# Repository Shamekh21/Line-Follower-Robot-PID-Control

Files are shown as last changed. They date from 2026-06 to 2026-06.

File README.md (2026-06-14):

# Line-Follower-Robot-PID-Control

An autonomous high-speed Line Follower Robot developed as part of the **Mobile Robots (MAM331)** course at **Benha University - Faculty of Engineering**.

The robot was designed, assembled, programmed, and tested to follow a predefined path using a **5-sensor infrared array** and a **PID control algorithm** for accurate and stable navigation.

The project successfully participated in a line follower competition organized during the course, achieving one of the fastest completion times on the track.

---

## 📸 Robot Design

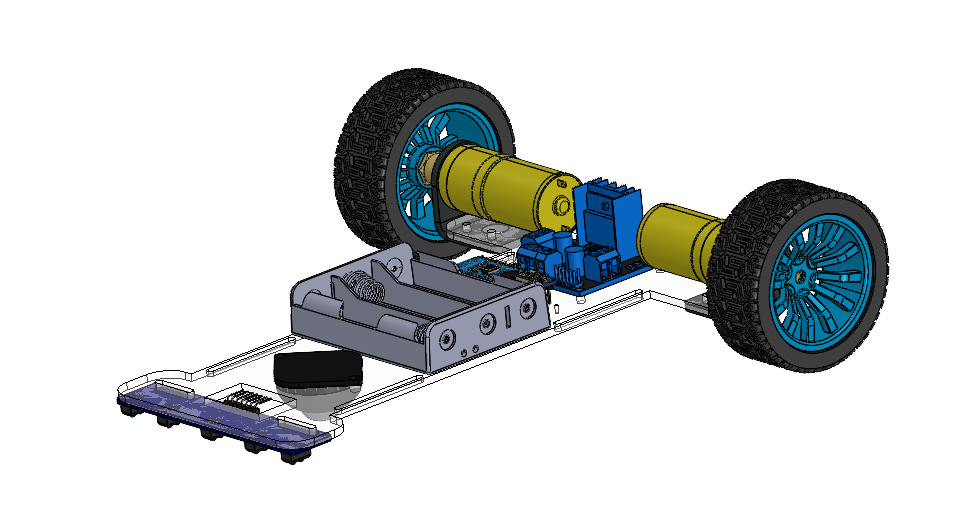
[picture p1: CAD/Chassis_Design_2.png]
Robot Design


The robot chassis was designed and assembled using **SolidWorks**, focusing on lightweight construction, stability, and efficient sensor placement for optimal line tracking performance.

---

## 🎥 Demonstration



---

# 🚀 Project Features

- Autonomous line tracking
- PID-based steering correction
- High-speed navigation
- Real-time sensor processing
- Lost-line recovery mechanism
- Optimized turning behavior
- Motor calibration support
- Differential drive locomotion
- Custom mechanical design

---
--# System Architecture

```text
IR Sensor Array
       │
       ▼
Error Calculation
       │
       ▼
PID Controller
       │
       ▼
Motor Speed Correction
       │
       ▼
L298N Driver
       │
       ▼
DC Motors
       │
       ▼
Robot Motion
```
---

# ⚙️ Hardware Components

| Component | Description |
|---|---|
| Arduino nano | Main controller |
| L298N Motor Driver | Motor control |
| 2 DC Geared Motors | Robot locomotion(DC Gear Motor JGA25-370 (780RPM - 12V)) |
| 5 IR Line Sensors | Line detection(TCRT5000 Tracking Line Follower Sensor) |
| Caster Wheel | Balance and support |
| Li-ion Battery Pack | Power supply |
| Custom Chassis | Mechanical structure |

---
# 📷 Hardware Overview

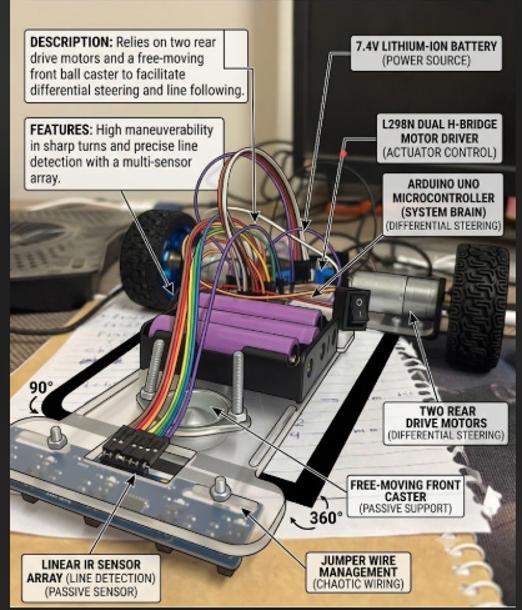
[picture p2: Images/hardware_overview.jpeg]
Hardware Overview


The figure illustrates the main hardware architecture of the robot, including the Arduino controller, L298N motor driver, infrared sensor array, differential drive system, battery pack, and chassis layout.
---
# 🧠 Control Strategy

The robot uses a **PID (Proportional-Integral-Derivative) Controller** to continuously minimize the tracking error between the robot's position and the detected line.

### PID Controller Advantages

- Smooth movement
- Fast response
- Reduced oscillation
- Improved stability at high speed
- Better corner handling

The implemented controller combines:

- Proportional Term (P)
- Integral Term (I)
- Derivative Term (D)

to generate steering corrections in real time.

---

# 📡 Sensor Configuration

The robot uses five infrared sensors positioned at the front of the chassis.

```text
[S1] [S2] [S3] [S4] [S5]
```

### Error Mapping

| Sensor Position | Error |
|---|---|
| Far Left | -2 |
| Left | -1 |
| Center | 0 |
| Right | +1 |
| Far Right | +2 |

This error value is used by the PID controller to calculate steering corrections.

---

# 🔧 Software Features

### Real-Time Sensor Reading

The robot continuously reads the state of all sensors to determine line position.

### PID Correction

Motor speeds are dynamically adjusted based on tracking error.

### Lost Line Recovery

If the line is temporarily lost, the robot automatically rotates toward the last known line direction until the path is detected again.

### Motor Calibration

Independent calibration values are included for left and right motors to compensate for hardware differences.

### High-Speed Optimization

The PID gains were experimentally tuned to achieve stable operation while maintaining high tracking speed.

---

# 🏎️ Competition Performance

The robot was tested during the Mobile Robots course competition.

### Achievements

- Successfully completed the course
- Stable tracking at high speed
- Accurate corner handling
- Fast recovery from tracking errors
- One of the fastest completion times during the competition

---

# 🛠️ Development Workflow

1. Mechanical Design using SolidWorks
2. Chassis Manufacturing and Assembly
3. Sensor Integration
4. Motor Driver Configuration
5. Arduino Programming
6. PID Tuning
7. Testing and Validation
8. Competition Deployment

---

# 💻 Technologies Used

- Arduino IDE
- Embedded C/C++
- PID Control
- SolidWorks
- Mobile Robotics
- Sensor-Based Navigation
- Differential Drive Systems

---

# 📚 Course

**Mobile Robots (MAM331)**

Faculty of Engineering  
Benha University

---

# 👨‍🏫 Supervision

**Dr. Muhammed Gaafar**

**Eng. Ahmed Adel Ghoneimy**

---

# 👥 Team Members

- Mahmoud Mohamed Shamekh
- Mohsen Hany Mohsen
- Youssef Ayad
- Barthinia Hany

---

# 🔗 GitHub Repository

Repository Link:

```
https://github.com/Shamekh21/Line-Follower-Robot-PID-Control.git
```

---

# 📌 Keywords

Robotics • Mobile Robots • Arduino • PID Control • Line Follower • Embedded Systems • Control Systems • Automation • Mechatronics • SolidWorks • Engineering

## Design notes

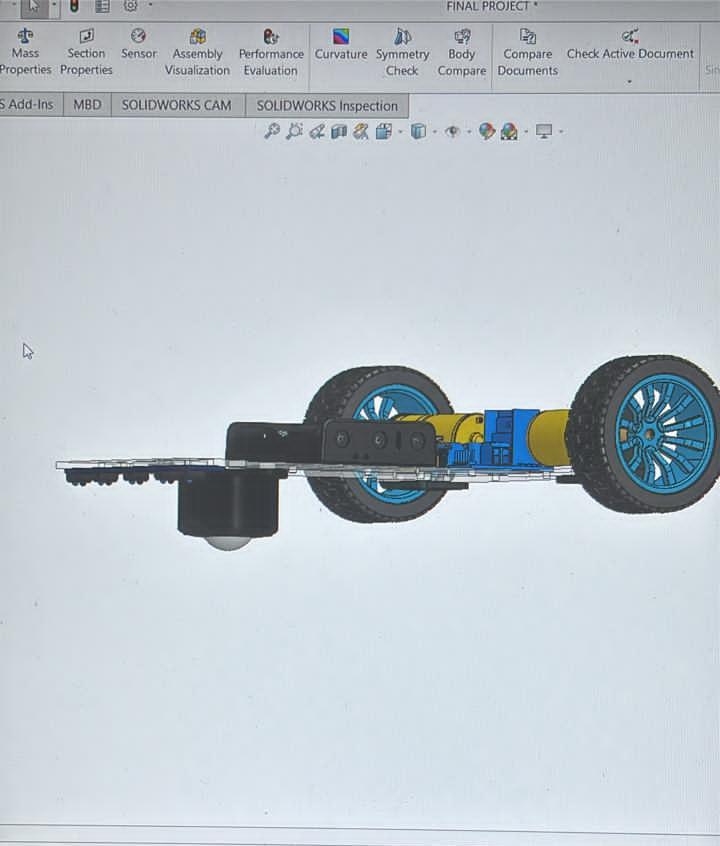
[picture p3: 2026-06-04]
CAD/line folower solid_3.jpeg

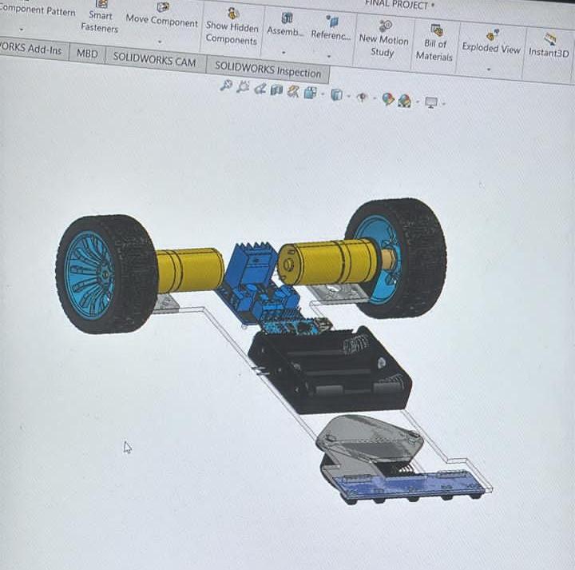
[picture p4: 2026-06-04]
CAD/line folower solid_2.jpeg

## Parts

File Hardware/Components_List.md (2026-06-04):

Arduino nano

L298N Motor Driver

2 DC Geared Motors:DC Gear Motor JGA25-370 (780RPM - 12V)

5 IR Line Tracking Sensors:TCRT5000 Tracking Line Follower Sensor

Caster Wheel

Li-ion Battery Pack

Custom Chassis Design

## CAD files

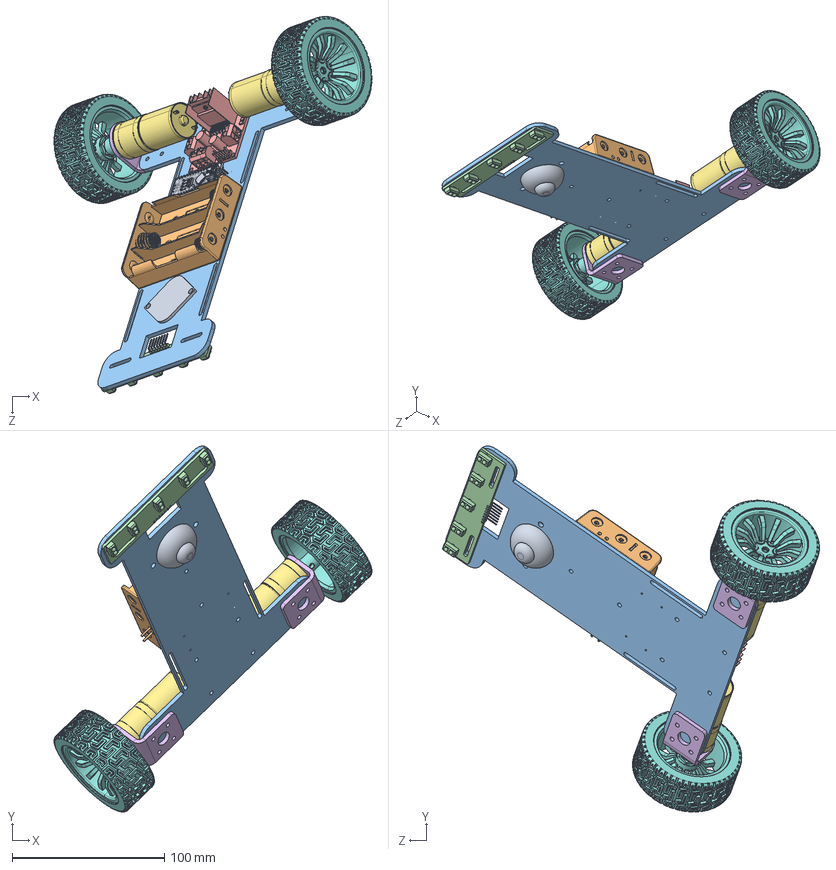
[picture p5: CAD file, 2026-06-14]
CAD/FINAL PROJECT.SLDASM
208.6 x 240.2 x 247.5 mm
Arduino_NANO_CH340.step
batteryCase18650x3.step
CHASSIS
IR sensor array.step
L298N Motor Driver.STEP
Motor Bracket JGA25.stp x 2
motor.STEP x 2
65mm蓝色轮胎总装-实际外径68mm.STEP x 2
BALL CASTER WHEEL

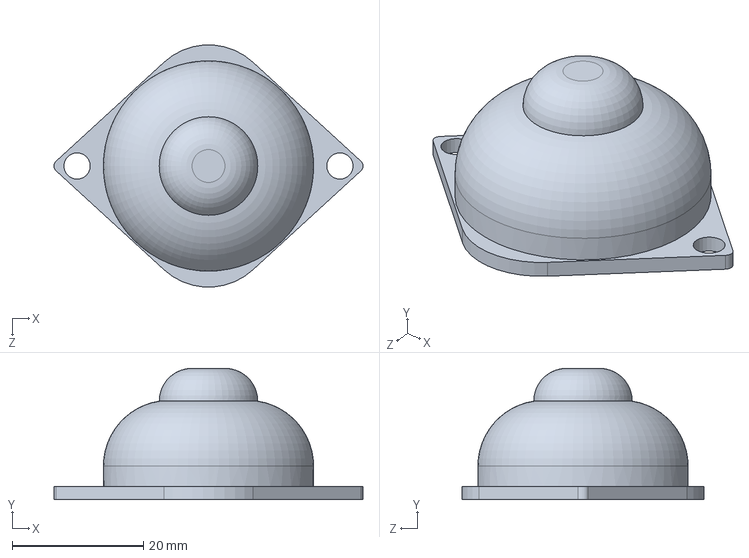
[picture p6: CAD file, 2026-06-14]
CAD/BALL CASTER WHEEL.SLDPRT
47.0 x 20.0 x 36.8 mm

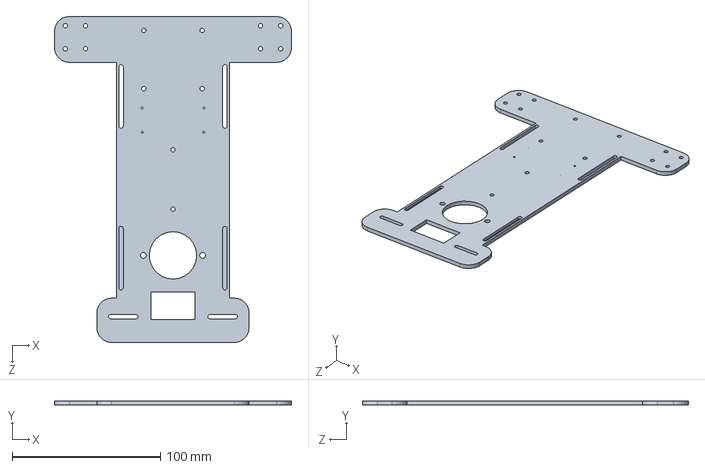
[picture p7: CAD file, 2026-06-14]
CAD/CHASSIS.SLDPRT
160.0 x 3.00 x 220.0 mm

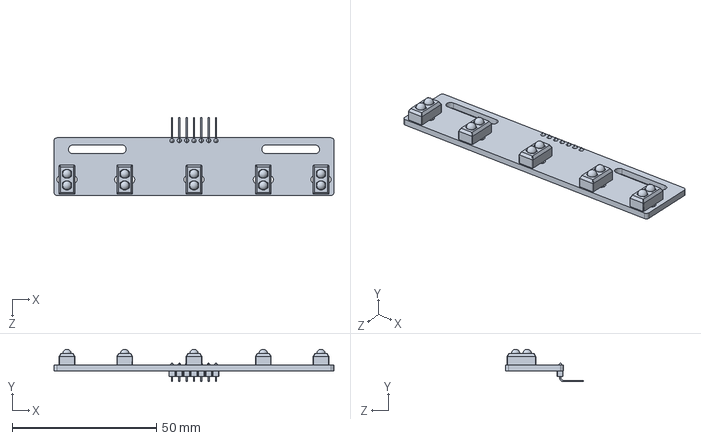
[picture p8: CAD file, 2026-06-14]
CAD/IR sensor array.step.SLDPRT
97.0 x 11.2 x 27.0 mm

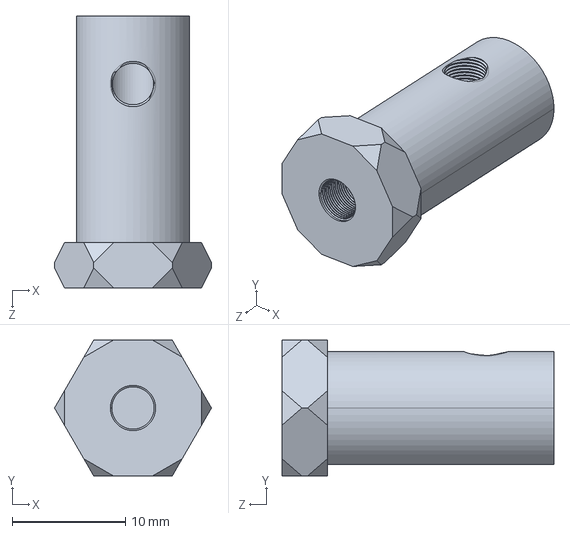
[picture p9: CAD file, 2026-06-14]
CAD/Coupler_4mm.STEP
13.9 x 12.0 x 24.0 mm

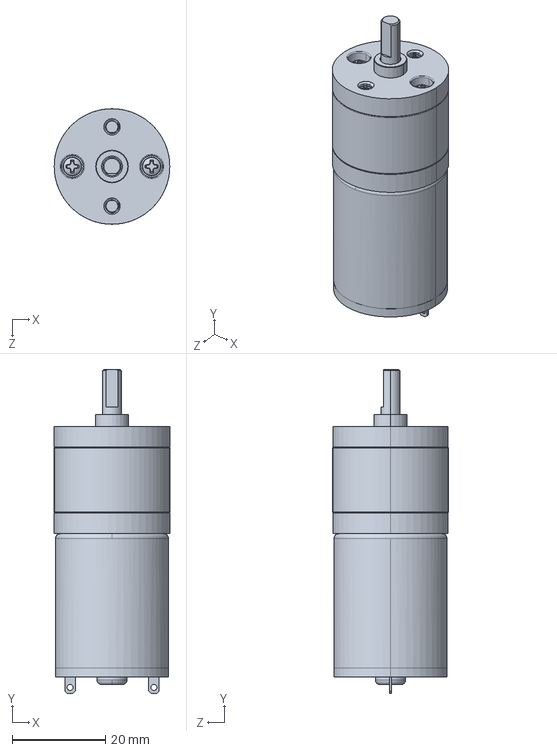
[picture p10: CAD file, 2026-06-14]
CAD/motor.STEP.SLDPRT
24.8 x 69.5 x 24.8 mm

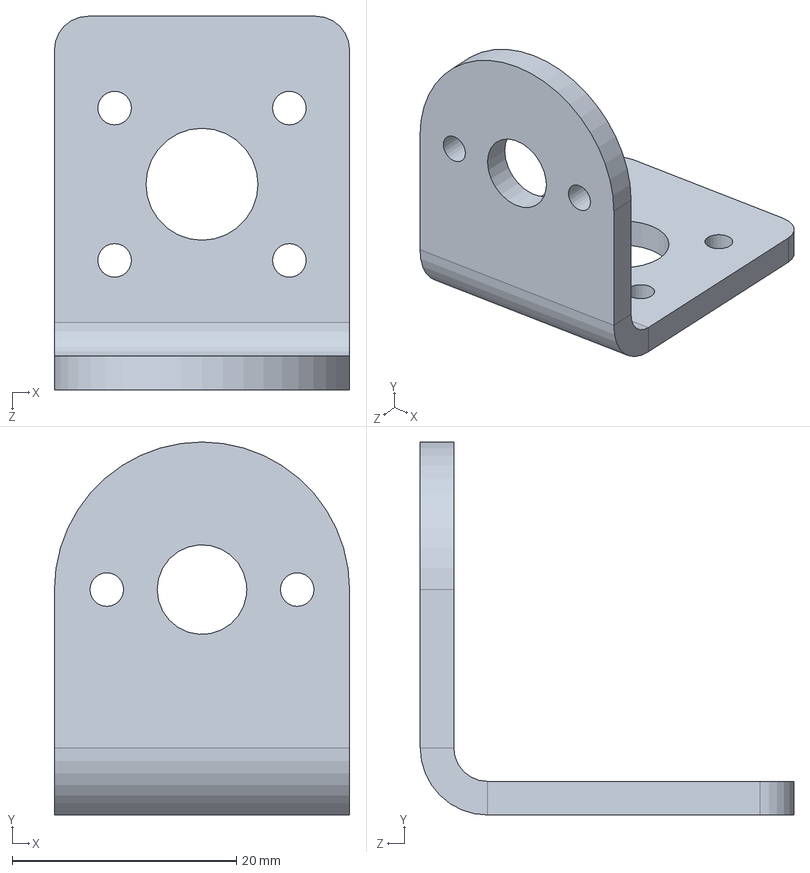
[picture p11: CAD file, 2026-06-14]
CAD/Motor Bracket JGA25.stp.SLDPRT
26.4 x 33.3 x 33.3 mm

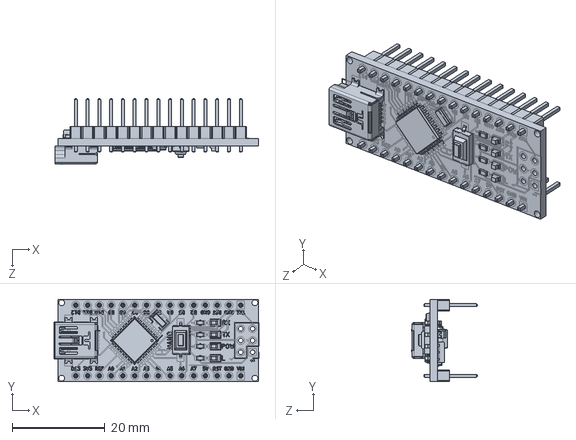
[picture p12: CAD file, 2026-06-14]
CAD/Arduino_NANO_CH340.step.SLDPRT
44.2 x 17.8 x 14.1 mm

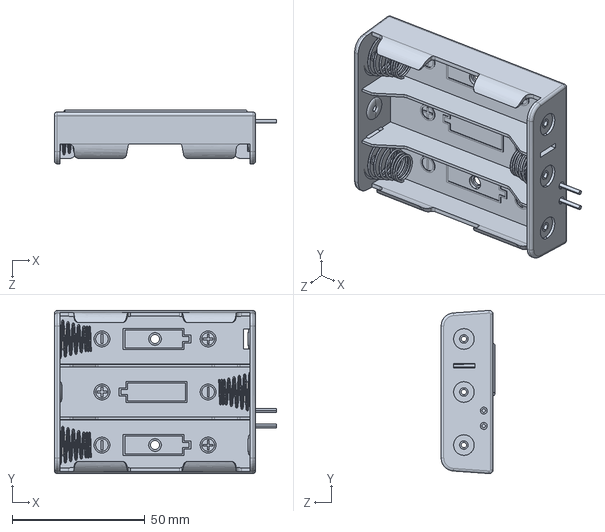
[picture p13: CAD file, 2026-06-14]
CAD/batteryCase18650x3.step.SLDPRT
83.7 x 61.5 x 20.3 mm

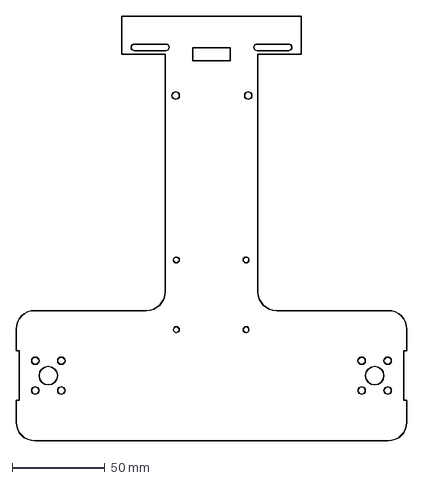
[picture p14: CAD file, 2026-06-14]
CAD/chasis.DXF
210.0 x 228.2 mm

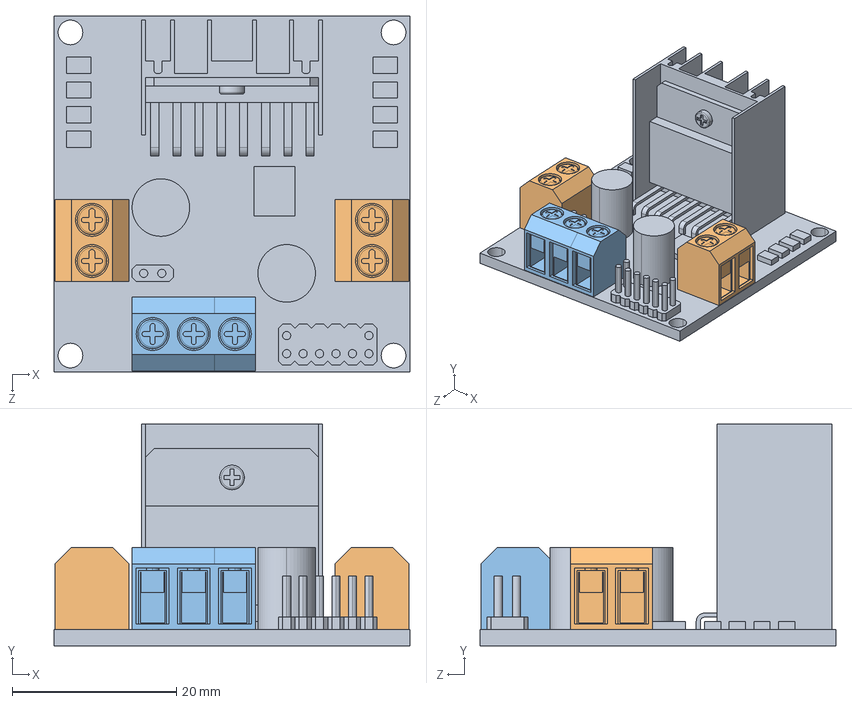
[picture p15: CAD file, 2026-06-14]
CAD/L298N Motor Driver.STEP
43.3 x 27.0 x 43.3 mm
Pcb.step
Pengunci.step x 2
Pengunci 2.step

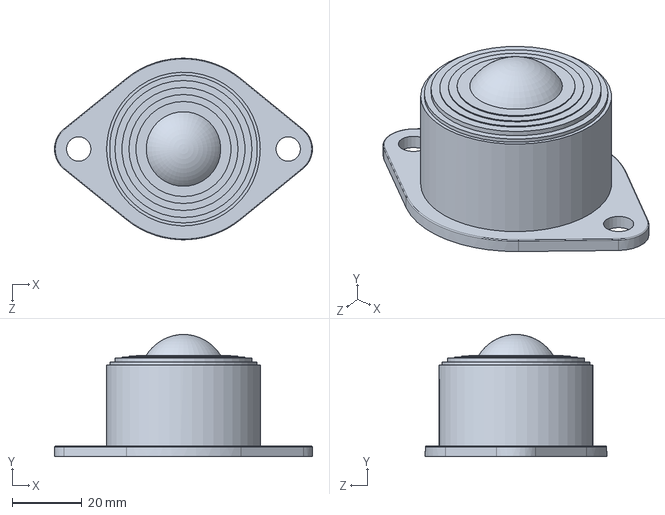
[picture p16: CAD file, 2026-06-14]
CAD/Caster Wheel.stp.SLDPRT
73.9 x 35.0 x 52.0 mm

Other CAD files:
CAD/motor.STEP
CAD/Coupler_4mm.step.SLDPRT
CAD/batteryCase18650x3.STEP
CAD/CHASSIS.DXF

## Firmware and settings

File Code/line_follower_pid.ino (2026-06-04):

// ===================== Motor Driver =====================
#define ENA 5
#define IN1 9
#define IN2 10
#define ENB 6
#define IN3 11
#define IN4 12

// ===================== Sensors ==========================
#define S1 8
#define S2 4
#define S3 13
#define S4 3
#define S5 2

const int sensorPins[5] = {S1, S2, S3, S4, S5};

// إذا الحساسات بتدي LOW على الأسود
const int BLACK = LOW;
const int WHITE = HIGH;

// ===================== Control ==========================
int baseSpeed = 120;
int maxSpeed  = 255;
int minSpeed  = 0;

// ===================== PID Tuned ========================
float Kp = 3.5;
float Kd = 1.8;
float Ki = 0.015;

// ===================== PID Variables ====================
float lastError = 0;
float integral  = 0;

// ===================== Timing ===========================
unsigned long lastTime = 0;
const int loopTime = 2;

// ===================== Motor Calibration ================
float motorTrimLeft  = 1.00;
float motorTrimRight = 1.00;

// ===================== Setup ============================
void setup() {
  pinMode(ENA, OUTPUT);
  pinMode(IN1, OUTPUT);
  pinMode(IN2, OUTPUT);

  pinMode(ENB, OUTPUT);
  pinMode(IN3, OUTPUT);
  pinMode(IN4, OUTPUT);

  for (int i = 0; i < 5; i++) {
    pinMode(sensorPins[i], INPUT);
  }

  Serial.begin(9600);

  stopMotors();
  delay(2000);
}

// ===================== Main Loop ========================
void loop() {
  if (millis() - lastTime < loopTime) return;
  lastTime = millis();

  // قراءة الحساسات
  int s1 = digitalRead(S1);
  int s2 = digitalRead(S2);
  int s3 = digitalRead(S3);
  int s4 = digitalRead(S4);
  int s5 = digitalRead(S5);

  // حساب الخطأ
  int error = getError(s1, s2, s3, s4, s5);

  // Debug على السيريال
  Serial.print(s1); Serial.print(" ");
  Serial.print(s2); Serial.print(" ");
  Serial.print(s3); Serial.print(" ");
  Serial.print(s4); Serial.print(" ");
  Serial.print(s5); Serial.print("  E=");
  Serial.println(error);

  // ===================== FIX #1 ========================
  // لو الخط ضاع: اتجاه الدوران صُحِّح
  // lastError < 0 → الخط كان على اليسار → ادور يسار
  // lastError >= 0 → الخط كان على اليمين → ادور يمين
  if (error == 100) {
    if (lastError < 0)
      turnLeftHard();   // كان على اليسار → ارجع يسار
    else
      turnRightHard();  // كان على اليمين → ارجع يمين
    return;
  }

  // ================= PID =================
  integral += error;
  integral = constrain(integral, -20, 20);

  // Derivative مع تخفيف
  float derivative = (error - lastError) * 0.7;

  float correction = (Kp * error) +
                     (Kd * derivative) +
                     (Ki * integral);

  correction = constrain(correction, -70, 70);

  lastError = error;

  // حساب السرعات
  int leftSpeed  = baseSpeed - correction;
  int rightSpeed = baseSpeed + correction;

  leftSpeed  = constrain((int)(leftSpeed  * motorTrimLeft),  minSpeed, maxSpeed);
  rightSpeed = constrain((int)(rightSpeed * motorTrimRight), minSpeed, maxSpeed);

  // Deadband
  if (error == 0) {
    forward(baseSpeed, baseSpeed);
  }
  else if (abs(error) == 1) {
    int smallCorrection = (int)(correction * 0.45);
    leftSpeed  = constrain(baseSpeed - smallCorrection, minSpeed, maxSpeed);
    rightSpeed = constrain(baseSpeed + smallCorrection, minSpeed, maxSpeed);
    forward(leftSpeed, rightSpeed);
  }
  else {
    forward(leftSpeed, rightSpeed);
  }
}

// ===================== FIX #2 ========================
// getError() مُحسَّنة - تغطي جميع حالات الحساسات المزدوجة والثلاثية
// تمنع الإرجاع الخاطئ لـ 100 (خط مفقود) وقت المنعطفات
int getError(int s1, int s2, int s3, int s4, int s5) {

  // كل الحساسات بيشوفوا أبيض فقط → الخط ضاع فعلًا
  if (s1 == WHITE && s2 == WHITE && s3 == WHITE && s4 == WHITE && s5 == WHITE)
    return 100;

  // ===== تقاطع أو خط عريض =====
  if (s1 == BLACK && s2 == BLACK && s3 == BLACK && s4 == BLACK && s5 == BLACK)
    return 0;  // تقاطع كامل → امشي مستقيم

  if (s2 == BLACK && s3 == BLACK && s4 == BLACK)
    return 0;  // خط عريض مركزي

  // ===== المنتصف =====
  if (s3 == BLACK && s2 == WHITE && s4 == WHITE)
    return 0;

  // ===== انحراف بسيط =====
  if (s2 == BLACK && s3 == WHITE)
    return -1;

  if (s4 == BLACK && s3 == WHITE)
    return 1;

  // ===== انحراف كبير =====
  if (s1 == BLACK && s2 == WHITE)
    return -2;

  if (s5 == BLACK && s4 == WHITE)
    return 2;

  // ===== حالات مزدوجة =====
  if (s2 == BLACK && s3 == BLACK)
    return -1;

  if (s3 == BLACK && s4 == BLACK)
    return 1;

  if (s1 == BLACK && s2 == BLACK)
    return -2;

  if (s4 == BLACK && s5 == BLACK)
    return 2;

  // ===== حالات ثلاثية (جديدة - تمنع الخطأ عند المنعطفات) =====
  if (s1 == BLACK && s2 == BLACK && s3 == BLACK)
    return -2;

  if (s3 == BLACK && s4 == BLACK && s5 == BLACK)
    return 2;

  // ===== حالة واحدة فقط على الأطراف =====
  if (s1 == BLACK)
    return -2;

  if (s5 == BLACK)
    return 2;

  // الخط ضاع فعلًا
  return 100;
}

// ===================== Motor Control ====================
void setLeftMotor(int speed) {
  speed = constrain(speed, -255, 255);
  if (speed >= 0) {
    digitalWrite(IN1, HIGH);
    digitalWrite(IN2, LOW);
    analogWrite(ENA, speed);
  } else {
    digitalWrite(IN1, LOW);
    digitalWrite(IN2, HIGH);
    analogWrite(ENA, -speed);
  }
}

void setRightMotor(int speed) {
  speed = constrain(speed, -255, 255);
  if (speed >= 0) {
    digitalWrite(IN3, HIGH);
    digitalWrite(IN4, LOW);
    analogWrite(ENB, speed);
  } else {
    digitalWrite(IN3, LOW);
    digitalWrite(IN4, HIGH);
    analogWrite(ENB, -speed);
  }
}

void forward(int leftSpeed, int rightSpeed) {
  setLeftMotor(leftSpeed);
  setRightMotor(rightSpeed);
}

// ===================== FIX #1 (دوران قوي مصحح) =========
// turnLeftHard: الموتور الأيمن للأمام، الأيسر للخلف
void turnLeftHard() {
  setLeftMotor(-100);
  setRightMotor(160);
}

// turnRightHard: الموتور الأيسر للأمام، الأيمن للخلف
void turnRightHard() {
  setLeftMotor(160);
  setRightMotor(-100);
}

void stopMotors() {
  setLeftMotor(0);
  setRightMotor(0);
}

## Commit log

2026-06-04 Add line follower PID control implementation
2026-06-04 CAD Files
2026-06-04 Rename line folower solid_1.png to Chassis_Design.png
